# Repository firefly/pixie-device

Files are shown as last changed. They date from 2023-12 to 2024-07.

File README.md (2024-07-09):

Firefly Pixie: Hardware
=======================

The hardware design, schematics and PCB layouts for the Firefly
Pixie Hardware Wallet for Ethereum (and ilk).

- [Firmware](https://github.com/firefly/pixie-firmware)
- [Case](https://github.com/firefly/pixie-case)

See the [CHANGELOG](./CHANGELOG.md) for high-level changes
between board revisions.

Tech Specs
----------

- **Processor:** ESP32-C3 (32-bit RISC-V)
- **Speed:** 160Mhz
- **Memory:** 400kb RAM, 16Mb Flash, 4kb eFuse
- **Inputs:** 4x tactile buttons
- **Outputs:**
  - 240x240px IPS 1.3" display (16-bit color; RGB565)
  - 4x RGB LED (WS2812B; 24-bit color; GRB888)
- **Conectivity:**
  - USB-C (power + JTAG/CDC-ACM)
  - BLE

Contributing
------------

- To modify the files, use [KiCad](https://www.kicad.org) (open-source EDA application)
- Sicne the `git diff` involved in modifying these files is somewhat opaque, please start a discussion first, so any changes can be coordinated

Photos
-----------

See the [output](./output/) folder for rendered schematics, PCBs
and 3D renders along with photos of the various revisions.

<p align="center">
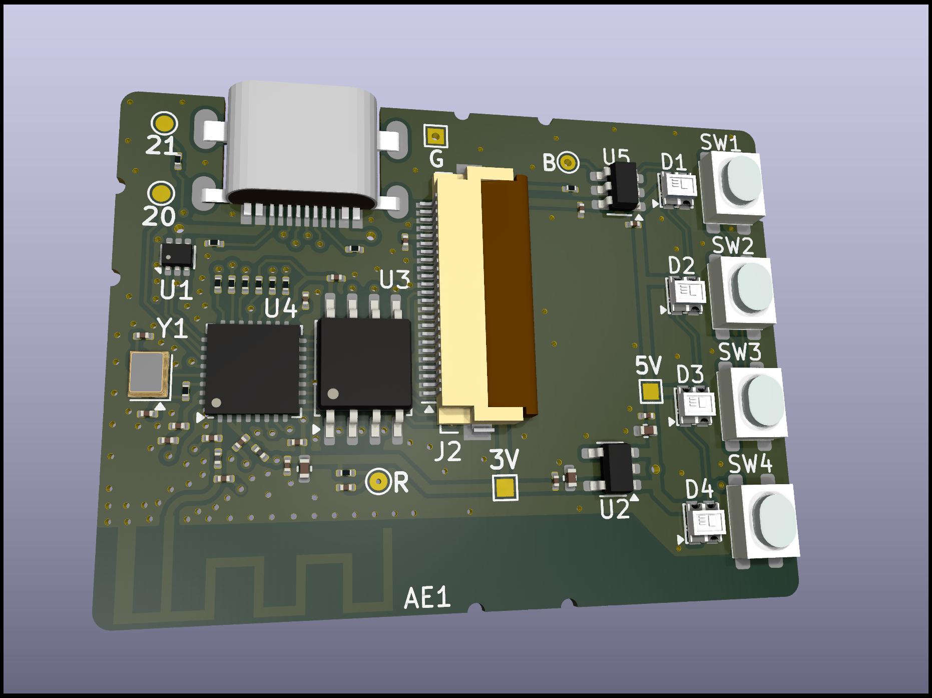
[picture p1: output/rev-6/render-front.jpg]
Front of Firefly Pixie
  
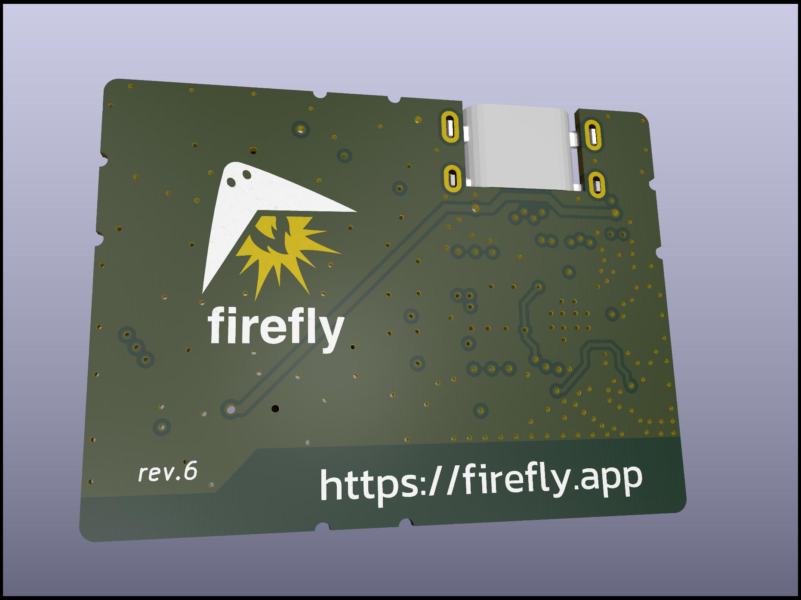
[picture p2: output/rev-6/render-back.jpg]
Back of Firefly Pixie
  
</p>

License
-------

MIT License.

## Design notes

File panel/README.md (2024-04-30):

Panelize
========

This folder uses [KiKit](https://github.com/yaqwsx/KiKit/tree/master) to
create panelized versions of the Firefly Pixie device.

Usage
-----

First, it is important to ensure the KiCad-specific Python runtime has
the KiKit library installed:

```shell
# MacOS
/Users/firefly> /Applications/KiCad/KiCad.app/Contents/Frameworks/Python.framework/Versions/Current/bin/pip3 install KiKit

# Windows
@TODO

# Linux
@TODO
```

Then the `./panelize.sh` can be run in this folder, which creates the
output `panel.kicad_pcb` in the same folder.

```shell
/Users/firefly/pixie-device/panel> ./panelize.sh
```

Renders
-------

<p align="center">
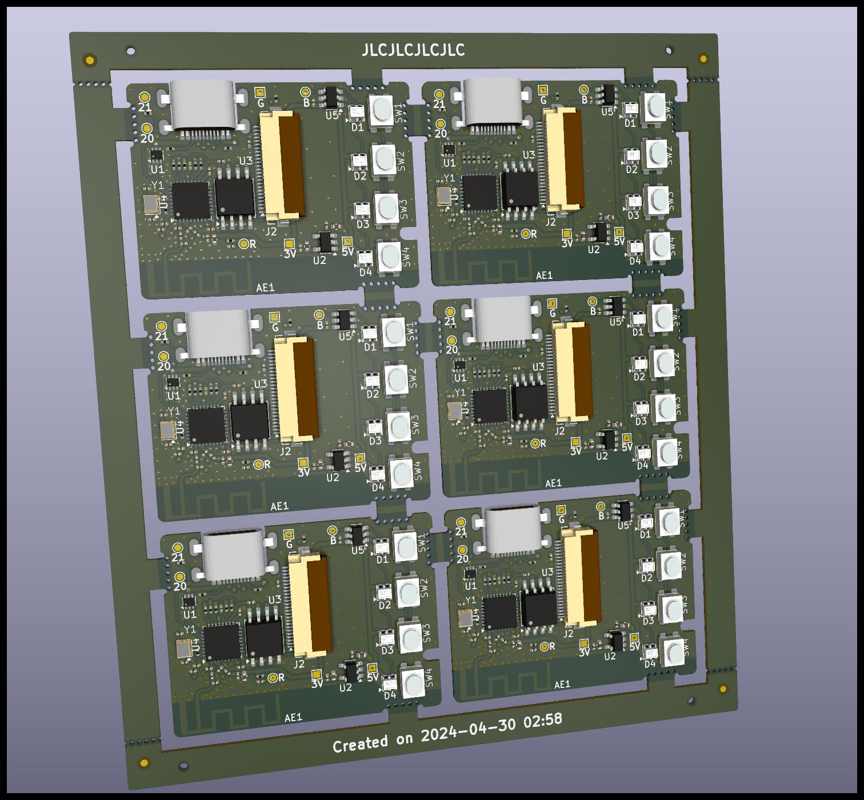
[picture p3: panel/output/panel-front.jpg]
Front of Firefly Pixie panel
  
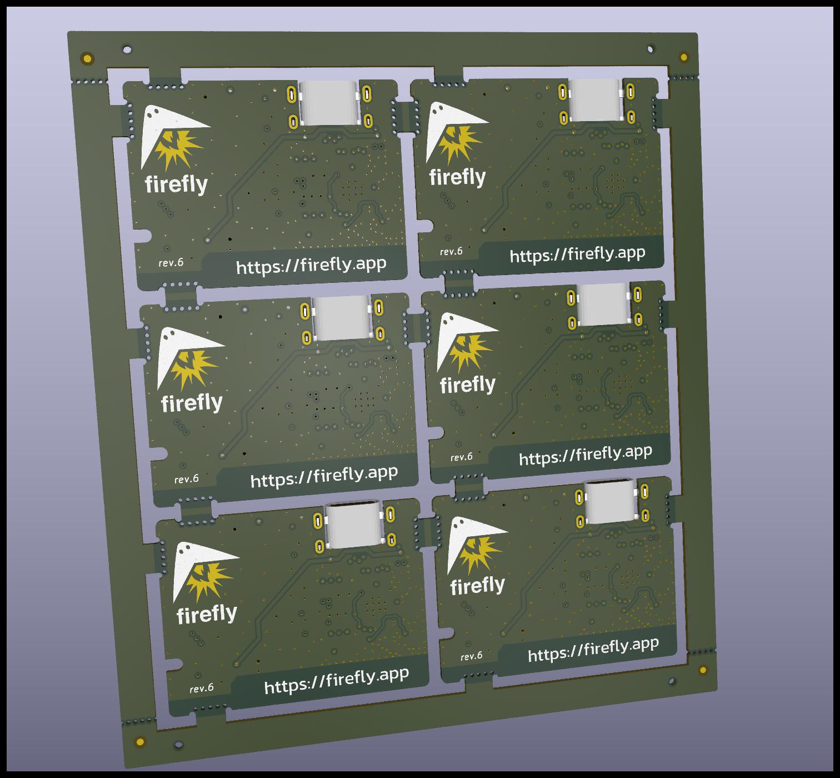
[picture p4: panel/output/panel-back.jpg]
Back of Firefly Pixie panel
  
</p>

<p align="center">
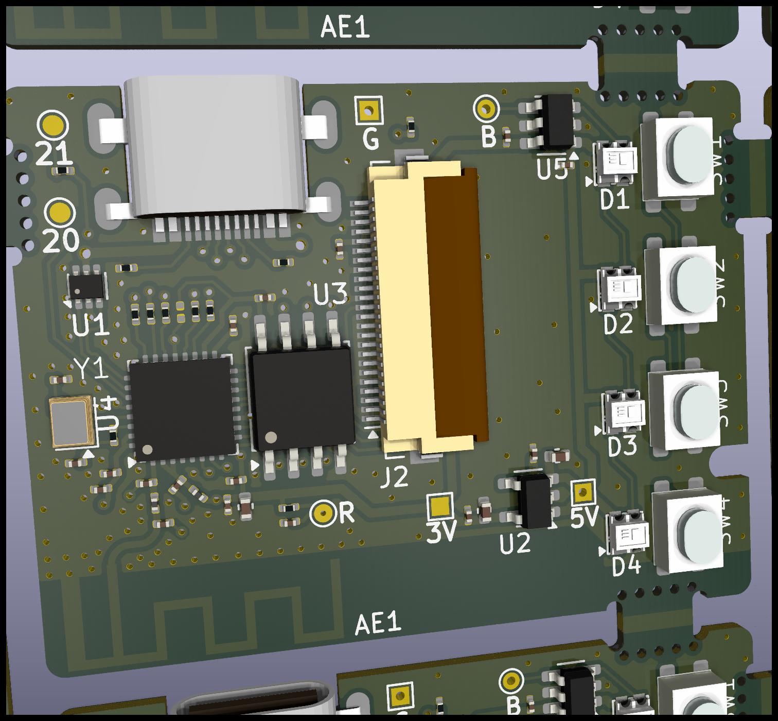
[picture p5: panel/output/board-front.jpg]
Front of Firefly Pixie panel single board
  
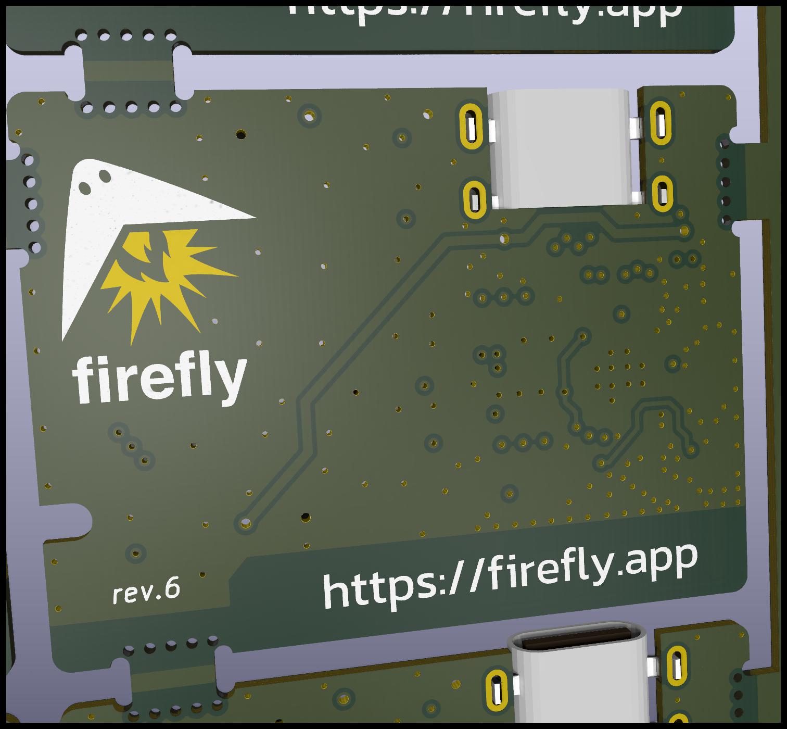
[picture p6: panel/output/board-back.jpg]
Back of Firefly Pixie panel single board
  
</p>

Notes
-----

If moving the tabs in the Firefly Pixie KiCad project (in the parent
folder), make sure to follow the convention it uses for tabs, to ensure
this panelize works correctly:

- The tab must be 4.4mm long, with a 0.5mm radius 180deg arc on both sides
- The "Tab" footprint should be flush and cneter with the tab,with its width set to "4.4mm"

License
-------

All files are licensed under the MIT license.

The PCB Footprints used are licensed uder the MIT license by KiKit.

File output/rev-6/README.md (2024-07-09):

Rev.6
=====

Schematic
---------

<p align="center">
  Schematic of Firefly Pixie: Blocks
  Schematic of Firefly Pixie: Power
</p>
<p align="center">
  Schematic of Firefly Pixie: MCU
  Schematic of Firefly Pixie: Output
</p>

3D Renders
----------

<p align="center">
  Front of Firefly Pixie Device
  Back of Firefly Pixie Device
</p>

<p align="center">
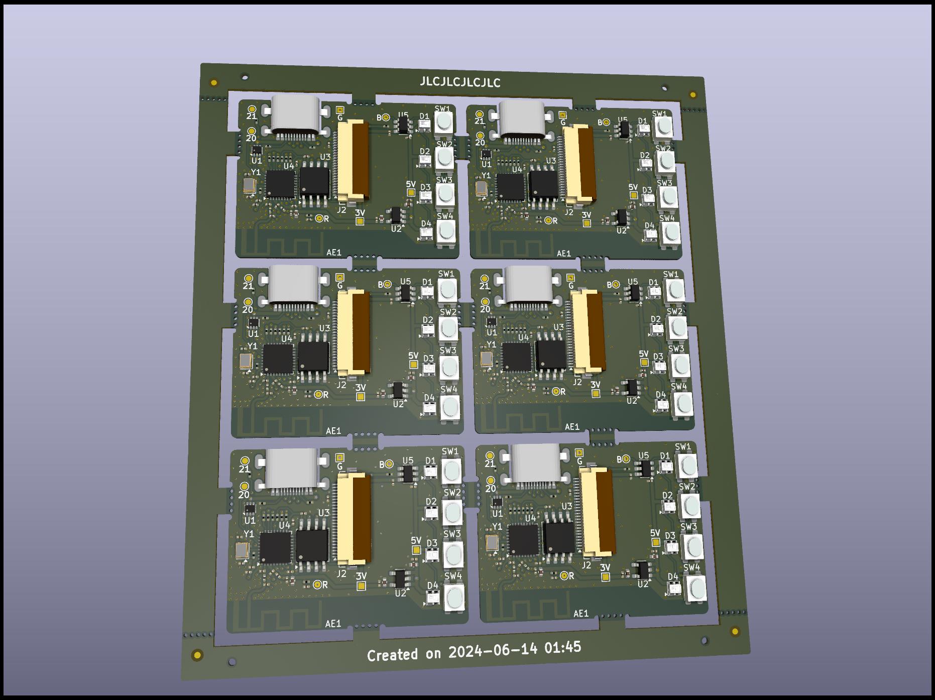
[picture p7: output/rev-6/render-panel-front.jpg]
Front of Firefly Pixie Panel
  
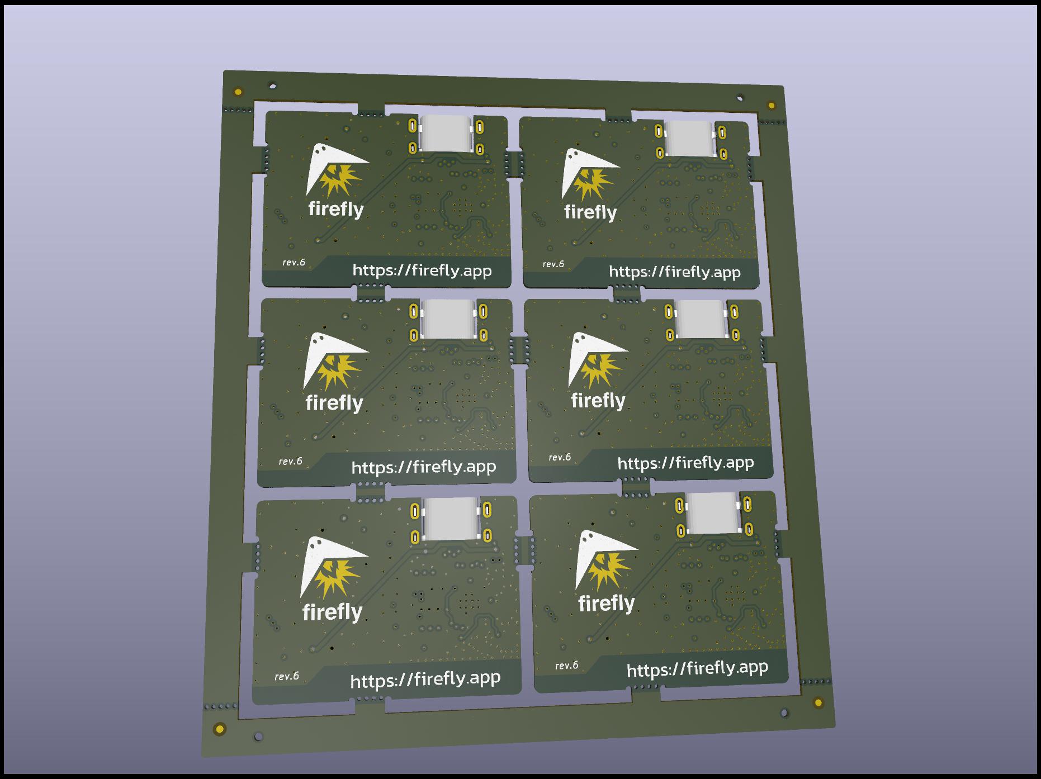
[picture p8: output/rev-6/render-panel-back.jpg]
Back of Firefly Pixie Panel
  
</p>

Photos
------

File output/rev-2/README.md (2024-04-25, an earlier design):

Rev.2
=====

Schematic
---------

<p align="center">
  Schematic of Firefly Pixie
</p>

3D Renders
----------

<p align="center">
  Front of Firefly Pixie
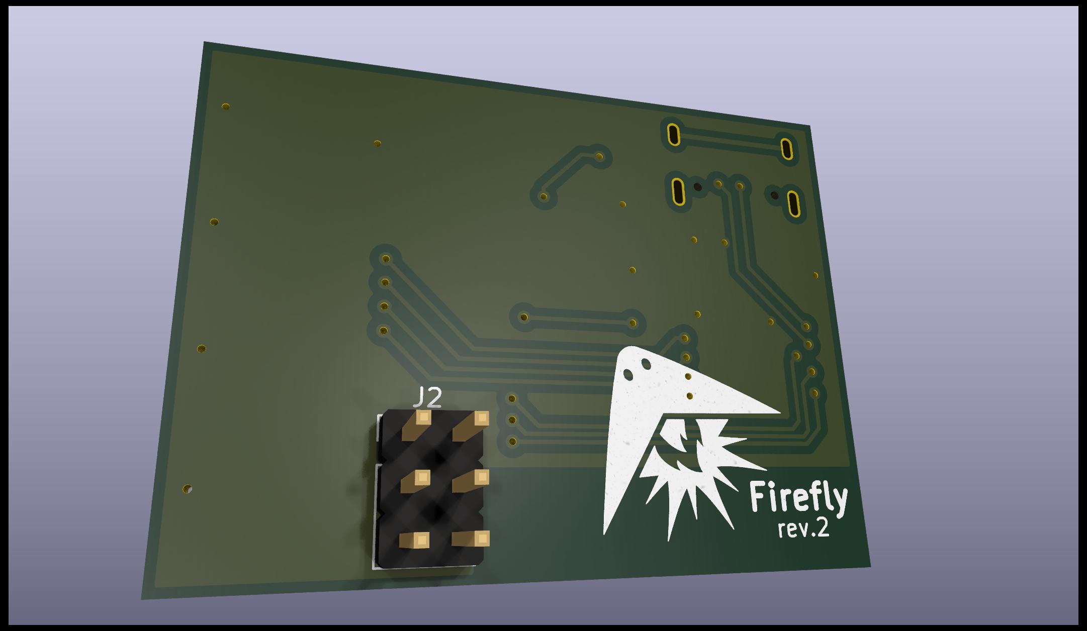
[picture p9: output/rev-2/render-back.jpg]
Back of Firefly Pixie
  
</p>

Photos
------

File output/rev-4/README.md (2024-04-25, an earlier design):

Rev.4
=====

Schematic
---------

<p align="center">
  Schematic of Firefly Pixie: Blocks
  Schematic of Firefly Pixie: Power
</p>
<p align="center">
  Schematic of Firefly Pixie: MCU
  Schematic of Firefly Pixie: Output
</p>

3D Renders
----------

<p align="center">
  Front of Firefly Pixie
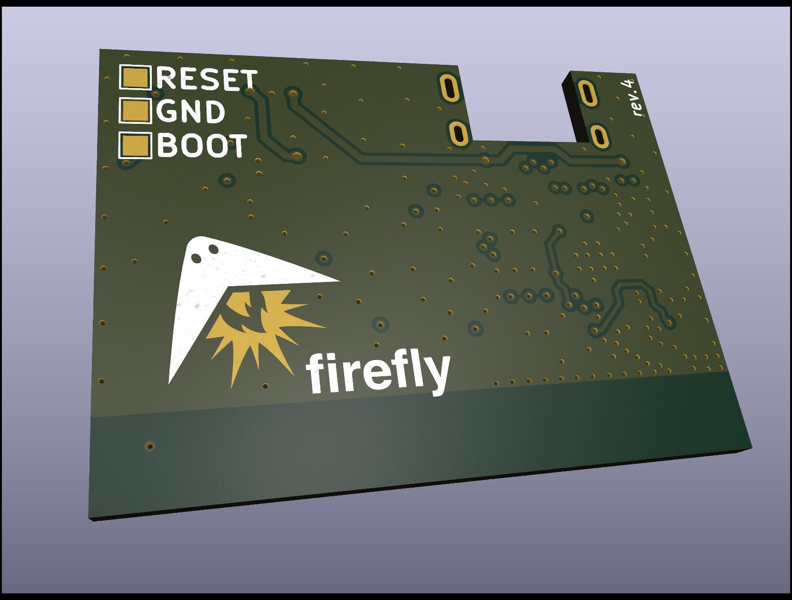
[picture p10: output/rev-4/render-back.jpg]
Back of Firefly Pixie
  
</p>

Photos
------

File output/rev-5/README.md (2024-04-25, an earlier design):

Rev.5
=====

Schematic
---------

<p align="center">
  Schematic of Firefly Pixie: Blocks
  Schematic of Firefly Pixie: Power
</p>
<p align="center">
  Schematic of Firefly Pixie: MCU
  Schematic of Firefly Pixie: Output
</p>

3D Renders
----------

<p align="center">
  Front of Firefly Pixie Panel
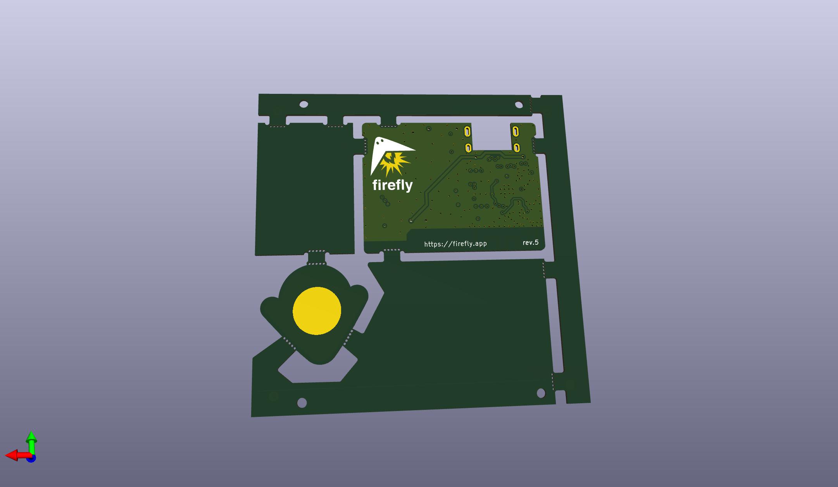
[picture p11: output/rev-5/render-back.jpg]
Back of Firefly Pixie Panel
  
</p>

<p align="center">
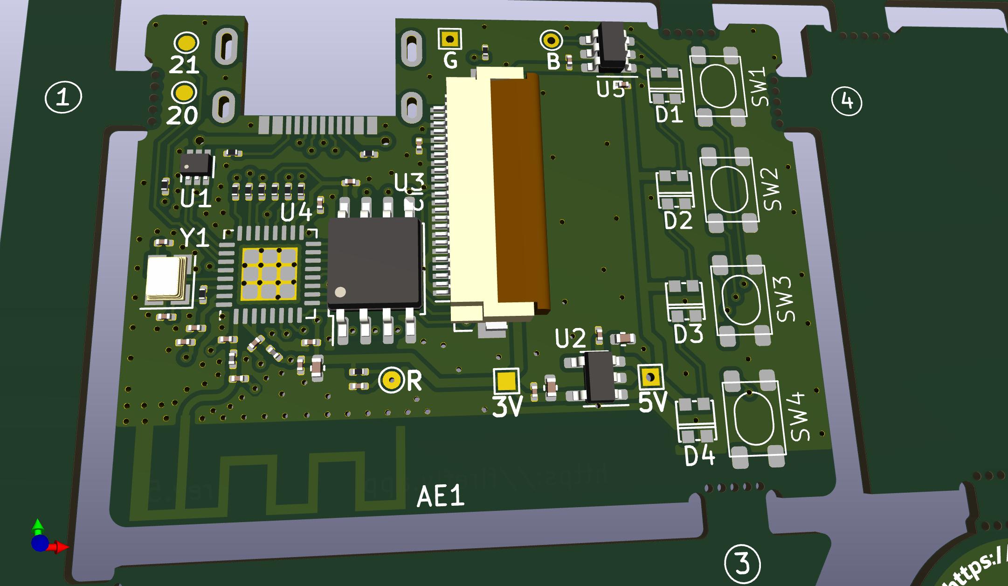
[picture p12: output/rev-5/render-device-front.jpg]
Front of Firefly Pixie Device
  
  Back of Firefly Pixie Device
</p>

<p align="center">
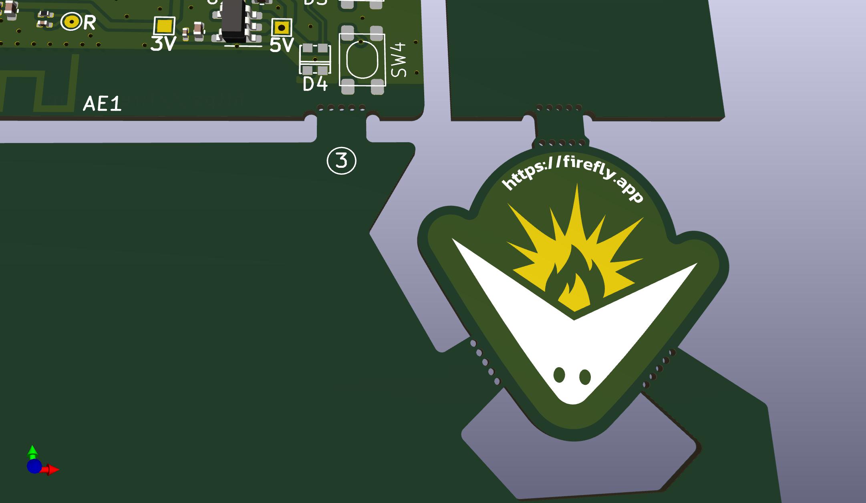
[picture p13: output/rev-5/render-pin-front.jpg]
Front of Firefly Pin
  
  Back of Firefly Pin
</p>

Photos
------

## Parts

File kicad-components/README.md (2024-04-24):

Firefly Compnoent Library
=========================

A bunch of random symbols and footprints for various
devices used for Firefly devices, development boards
and other tools.

License
-------

MIT License.

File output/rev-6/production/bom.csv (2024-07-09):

Designator | Footprint | Quantity | Value | LCSC Part #
C1_6, C1_5, C1_4, C1_3, C1_2, C1, C17_6, C17_5, C17_4, C17_3, C17_2, C17, C4_6, C4_5, C4_4, C4_3, C4_2, C4 | 0402 | 18 | 10u | C315248
C10_6, C10_5, C10_4, C10_3, C10_2, C10, C12_6, C12_5, C12_4, C12_3, C12_2, C12 | 0201 | 12 | 1u | C170153
C11_6, C11_5, C11_4, C11_3, C11_2, C11, C13_6, C13_5, C13_4, C13_3, C13_2, C13, C15_6, C15_5, C15_4, C15_3, C15_2, C15, C16_6, C16_5, C16_4, C16_3, C16_2, C16, C18_6, C18_5, C18_4, C18_3, C18_2, C18, C19_6, C19_5, C19_4, C19_3, C19_2, C19, C2_6, C2_5, C2_4, C2_3, C2_2, C2, C20_6, C20_5, C20_4, C20_3, C20_2, C20, C3_6, C3_5, C3_4, C3_3, C3_2, C3, C7_6, C7_5, C7_4, C7_3, C7_2, C7 | 0201 | 60 | 100n | C284966
C14_6, C14_5, C14_4, C14_3, C14_2, C14 | 0201 | 6 | 10n | C76941
C5_6, C5_5, C5_4, C5_3, C5_2, C5, C8_6, C8_5, C8_4, C8_3, C8_2, C8 | 0201 | 12 | 3p3 | C258460
C6_6, C6_5, C6_4, C6_3, C6_2, C6, C9_6, C9_5, C9_4, C9_3, C9_2, C9 | 0201 | 12 | 10p | C272871
D1_6, D1_5, D1_4, D1_3, D1_2, D1, D2_6, D2_5, D2_4, D2_3, D2_2, D2, D3_6, D3_5, D3_4, D3_3, D3_2, D3, D4_6, D4_5, D4_4, D4_3, D4_2, D4 | WS2812B | 24 | WS2812B | C2976072
J1_6, J1_5, J1_4, J1_3, J1_2, J1 | USB_C_SINK | 6 | ~ | C2906289
J2_6, J2_5, J2_4, J2_3, J2_2, J2 | JUSHUO_FPC_24 | 6 | ~ | C262669
L1_6, L1_5, L1_4, L1_3, L1_2, L1, L2_6, L2_5, L2_4, L2_3, L2_2, L2 | 0201 | 12 | 2n2 | C98041
R1_6, R1_5, R1_4, R1_3, R1_2, R1, R2_6, R2_5, R2_4, R2_3, R2_2, R2, R3_6, R3_5, R3_4, R3_3, R3_2, R3 | 0201 | 18 | 5K1 | C274341
R10_6, R10_5, R10_4, R10_3, R10_2, R10, R6_6, R6_5, R6_4, R6_3, R6_2, R6, R7_6, R7_5, R7_4, R7_3, R7_2, R7, R8_6, R8_5, R8_4, R8_3, R8_2, R8, R9_6, R9_5, R9_4, R9_3, R9_2, R9 | 0201 | 30 | 100R | C77623
R11_6, R11_5, R11_4, R11_3, R11_2, R11 | 0201 | 6 | 499R | C4354889
R12_6, R12_5, R12_4, R12_3, R12_2, R12 | 0201 | 6 | 10R | C304508
R4_6, R4_5, R4_4, R4_3, R4_2, R4 | 0201 | 6 | 22R | C270355
SW1_6, SW1_5, SW1_4, SW1_3, SW1_2, SW1, SW2_6, SW2_5, SW2_4, SW2_3, SW2_2, SW2, SW3_6, SW3_5, SW3_4, SW3_3, SW3_2, SW3, SW4_6, SW4_5, SW4_4, SW4_3, SW4_2, SW4 | button-oval | 24 | ~ | C720479
U1_6, U1_5, U1_4, U1_3, U1_2, U1 | SOT-563 | 6 | USBLC6-2SC6 | C2827693
U2_6, U2_5, U2_4, U2_3, U2_2, U2 | SOT-23-5 | 6 | SPX3819M5-L-3-3 | C5370980
U3_6, U3_5, U3_4, U3_3, U3_2, U3 | SOIC-8_5.23x5.23mm_P1.27mm | 6 | W25Q128JVS | C97521
U4_6, U4_5, U4_4, U4_3, U4_2, U4 | QFN-32-1EP_5x5mm_P0.5mm_EP3.45x3.45mm | 6 | ESP32-C3 | C2838500
U5_6, U5_5, U5_4, U5_3, U5_2, U5 | SOT-23-6 | 6 | SN74LVC1T45DBV | C168856
Y1_6, Y1_5, Y1_4, Y1_3, Y1_2, Y1 | crystal_2520 | 6 | 40Mhz | C409424

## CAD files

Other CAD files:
kicad-components/3d-models/button-oval.skp
kicad-components/3d-models/usb-c-sink-8.skp
kicad-components/3d-models/ws2812c-2020-v1.skp

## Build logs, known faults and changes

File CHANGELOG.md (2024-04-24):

Change Log
==========

Since the KiCAD files don't diff well, this list of changes
is maintained in a relatively manual manner, designed to help
keep developers up to date on the more broad cahnges made to
the device hardware.

Rev.6
-----

- Moved LEDK trace to B.cu (from In2.cu)
- Updated footprint for Crystal to match newer part and allow more space for the GPIO traces
- Updated all files and footprints from KiCAD 7 to KiCAD 8
- Added 3D models for Oval Button and WS2812c
- PCB Batch:
  - X devices
  - ENIG, 0.8mm, mouse-bites, purple mask
  - Panel: 2x3 devices, 100mm x 100mm panel

Rev.5
-----

- added GPIO 20 and 21 pads for debugging and extending hardware interfaces (including adding 499 ohm resistor to GPIO 21)
- Added test points for v5, v3.3, reset, boot and ground for debugging and extending hardware
- Added 3 more LED; one per button
- Use mouse bites instead of V-cut for rounded corners and better exposing the trench for the sunk USB port
- Added firefly pin punch out to test panelizing
- Relocated regulator for better FPC clearance
- Changed FPC part and footprint due to inventory constraints
- Added solder paste to USB shield PTH for better structural support
- PCB Batch
  - 25 devices
  - ENIG, 0.8mm, mouse-bites, green mask
  - Panel (testing): 1 device + 1 pin per, 70mm x 70mm panel

Rev.4
-----

- added LED to button 2 along with level shifter
- change logo flame to B.Mask from silkscreen so exposed copper is used for flame
- Change to Esp32 c3 chip with external 16mb storage (based on the WROOM layout)
- PCB Batch
  - 10 devices
  - HASL, 1.6mm, v-cut, green mask

Rev.2
-----

- Initial ESP32-c3 based device
- Uses ESP32c3-mini-1 module
- PCB Batch
  - 10 devices
  - HASL, 1.6mm, v-cut, green mask

Notes
-----

Early prototypes were based on ATmega and had multiple versions
in flight, prior to establishing a clear versioning policy. As
such there is a prior `rev.2` board completely unrelated to the

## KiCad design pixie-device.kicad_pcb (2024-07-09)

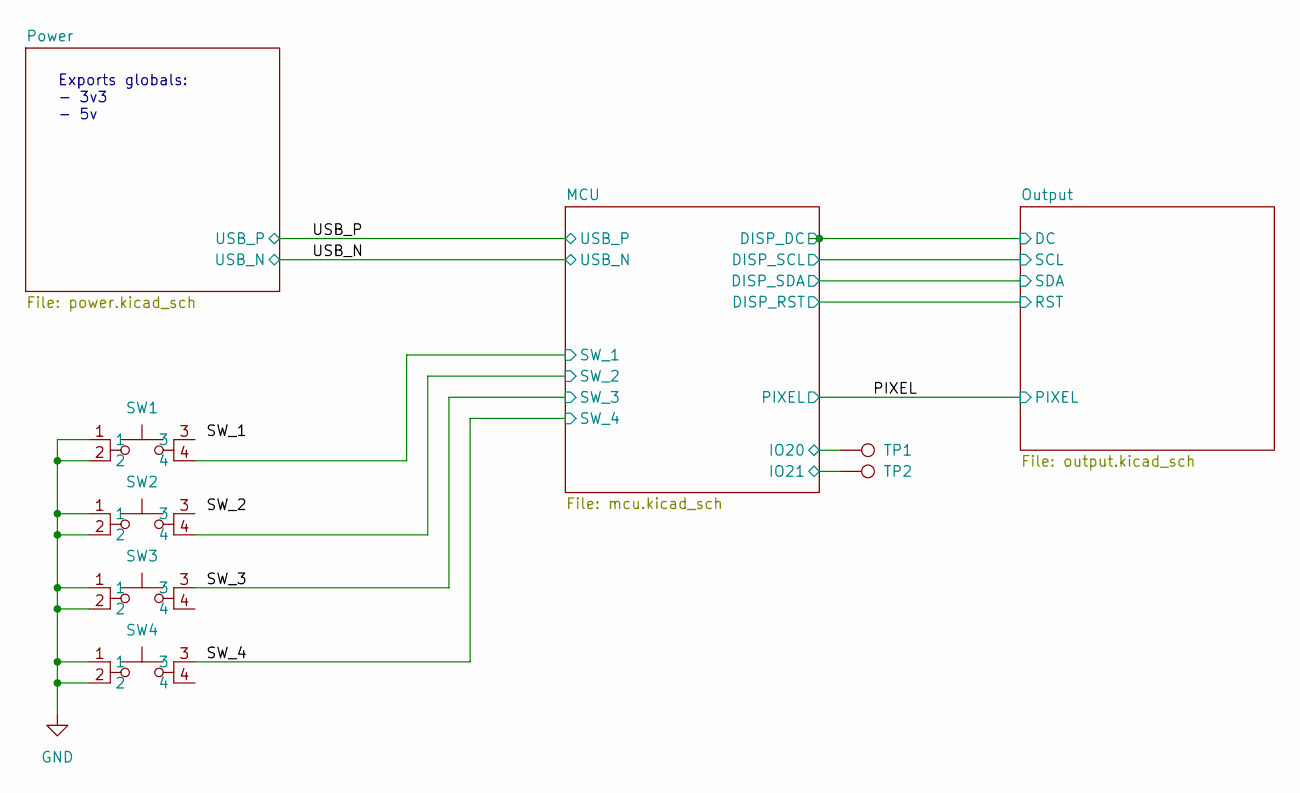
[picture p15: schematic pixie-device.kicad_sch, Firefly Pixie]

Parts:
SW1, SW2, SW3, SW4: button-oval; MPN C720479
TP1, TP2: TestPoint; TestPoint_Pad_D1.0mm

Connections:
/MCU/IO20: TP1.1; also elsewhere on the board
/MCU/IO21: TP2.1; also elsewhere on the board
/MCU/SW_1: SW1.4; also elsewhere on the board
/MCU/SW_2: SW2.4; also elsewhere on the board
/SW_3: SW3.3; also elsewhere on the board
/SW_4: SW4.3; also elsewhere on the board
GND: SW1.1, SW1.2, SW2.1, SW2.2, SW3.1, SW3.2, SW4.1, SW4.2; also elsewhere on the board

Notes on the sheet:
Exports globals: - 3v3 - 5v

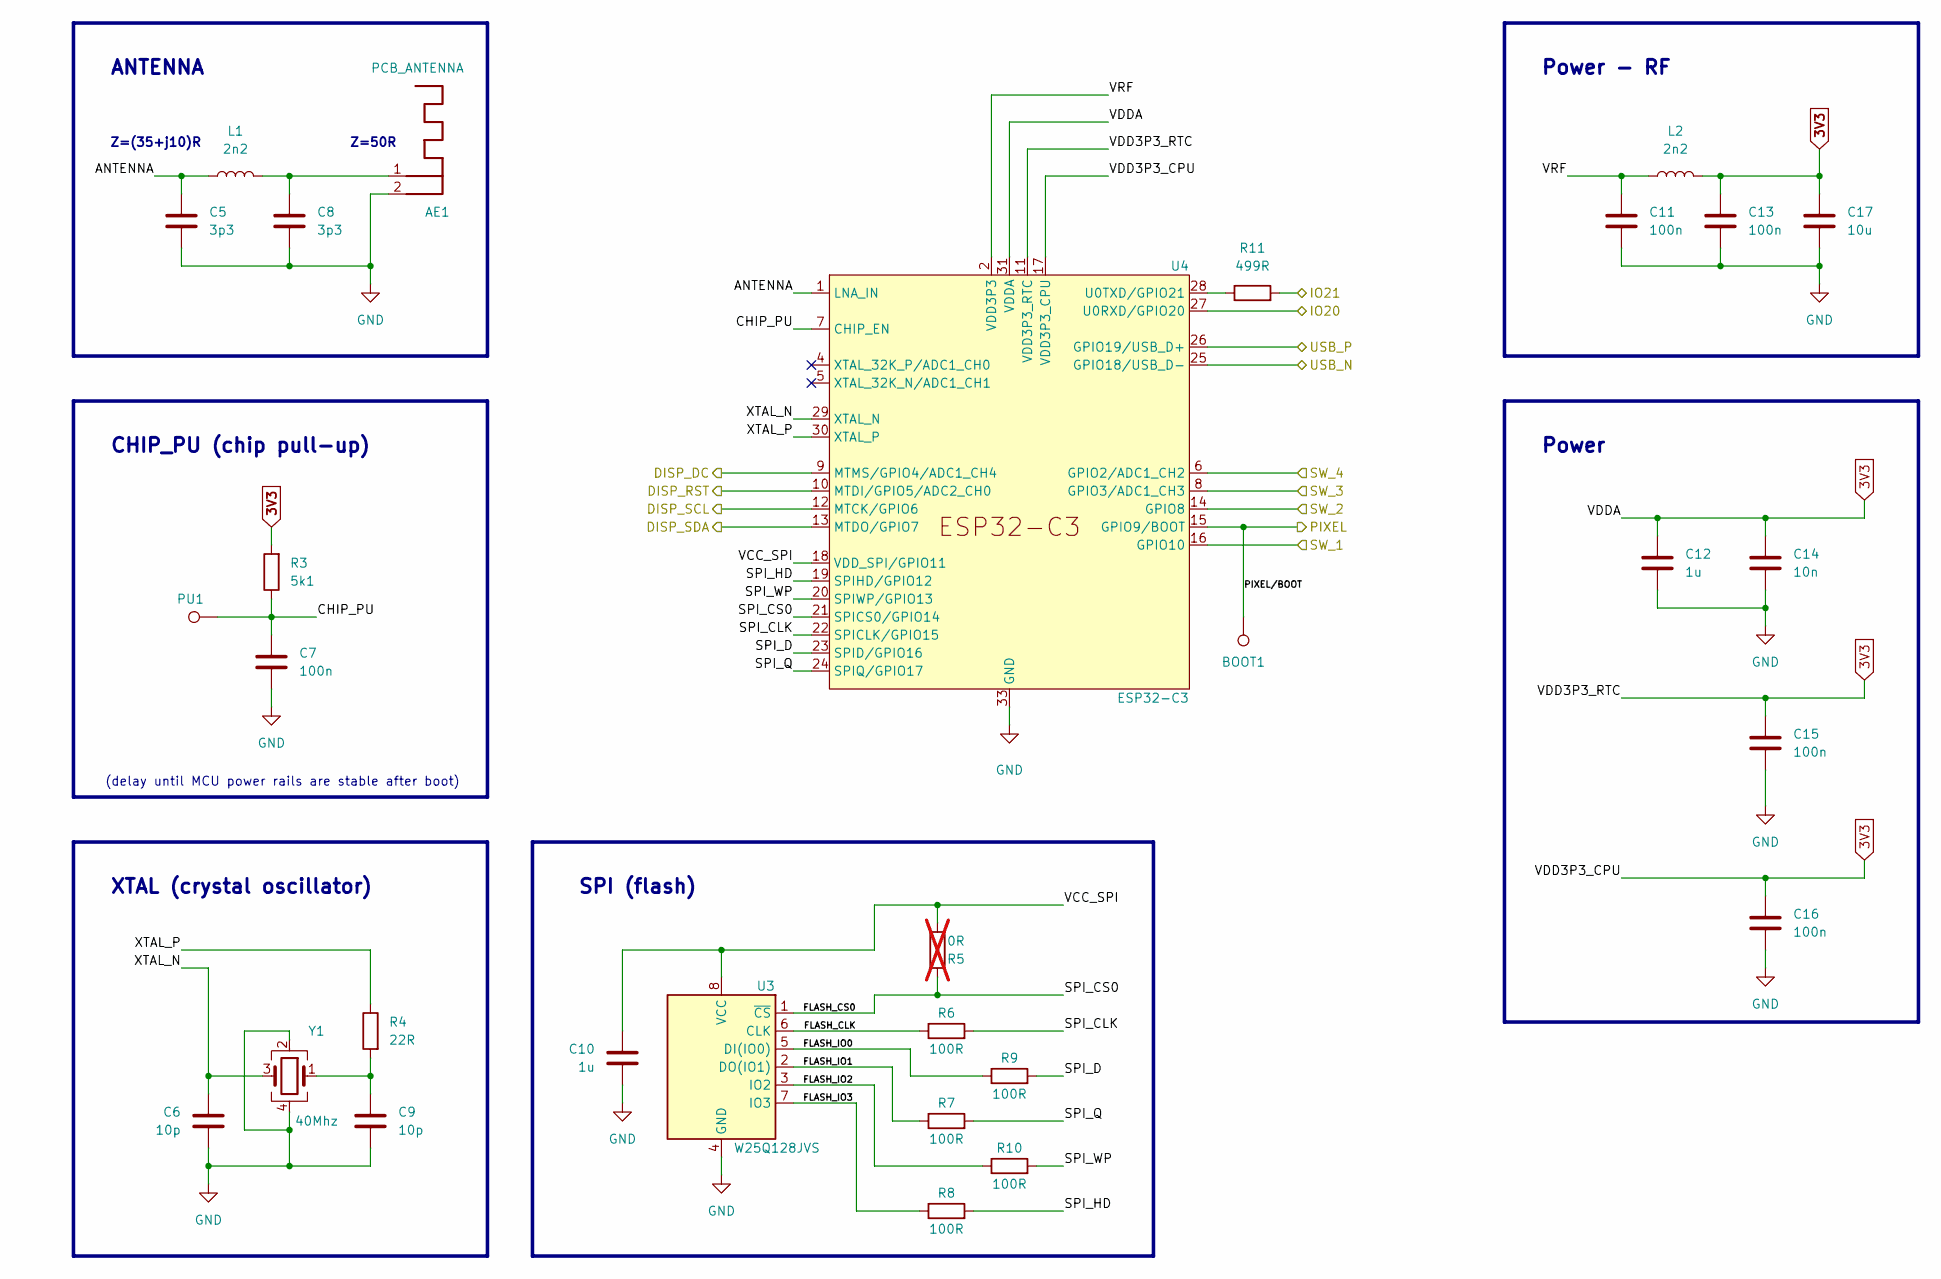
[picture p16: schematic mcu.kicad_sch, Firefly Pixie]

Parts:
AE1: PCB_ANTENNA; PCB_Antenna
BOOT1: TestPoint; TestPoint_Pad_D1.0mm
C5, C8: 3p3; C_0201_0603Metric; MPN C258460
C6, C9: 10p; C_0201_0603Metric; MPN C272871
C7, C11, C13, C15, C16: 100n; C_0201_0603Metric; MPN C284966
C10, C12: 1u; C_0201_0603Metric; MPN C170153
C14: 10n; C_0201_0603Metric; MPN C76941
C17: 10u; C_0402_1005Metric; MPN C315248
L1, L2: 2n2; L_0201_0603Metric; MPN C98041
PU1: TestPoint; TestPoint_Pad_D1.0mm
R3: 5k1; R_0201_0603Metric; MPN C274341
R4: 22R; R_0201_0603Metric; MPN C270355
R5: 0R; R_0201_0603Metric; not fitted
R6, R7, R8, R9, R10: 100R; R_0201_0603Metric; MPN C77623
R11: 499R; R_0201_0603Metric; MPN C4354889
U3: W25Q128JVS; SOIC-8_5.23x5.23mm_P1.27mm; MPN C97521
U4: ESP32-C3; QFN-32-1EP_5x5mm_P0.5mm_EP3.45x3.45mm; MPN C2838500
Y1: 40Mhz; crystal_2520; MPN_old C255973

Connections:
3V3: C12.1, C13.1, C14.1, C15.1, C16.1, C17.1, L2.2, R3.2, U4.11 (VDD3P3_RTC), U4.17 (VDD3P3_CPU), U4.31 (VDDA), U4.32 (VDDA); also elsewhere on the board
/MCU/ANTENNA: C5.1, L1.1, U4.1 (LNA_IN)
/MCU/CHIP_PU: C7.1, PU1.1, R3.1, U4.7 (CHIP_EN)
/MCU/DISP_DC: U4.9 (MTMS/GPIO4/ADC1_CH4); also elsewhere on the board
/MCU/DISP_RST: U4.10 (MTDI/GPIO5/ADC2_CH0); also elsewhere on the board
/MCU/DISP_SCL: U4.12 (MTCK/GPIO6); also elsewhere on the board
/MCU/DISP_SDA: U4.13 (MTDO/GPIO7); also elsewhere on the board
/MCU/FLASH_CLK: R6.1, U3.6 (CLK)
/MCU/FLASH_CS0: R5.2, U3.1 (~CS), U4.21 (SPICS0/GPIO14)
/MCU/FLASH_IO0: R9.1, U3.5 (DI(IO0))
/MCU/FLASH_IO1: R7.1, U3.2 (DO(IO1))
/MCU/FLASH_IO2: R10.1, U3.3 (IO2)
/MCU/FLASH_IO3: R8.1, U3.7 (IO3)
/MCU/IO20: U4.27 (U0RXD/GPIO20); also elsewhere on the board
/MCU/IO21: R11.2; also elsewhere on the board
/MCU/SPI_CLK: R6.2, U4.22 (SPICLK/GPIO15)
/MCU/SPI_D: R9.2, U4.23 (SPID/GPIO16)
/MCU/SPI_HD: R8.2, U4.19 (SPIHD/GPIO12)
/MCU/SPI_Q: R7.2, U4.24 (SPIQ/GPIO17)
/MCU/SPI_WP: R10.2, U4.20 (SPIWP/GPIO13)
/MCU/SW_1: U4.16 (GPIO10); also elsewhere on the board
/MCU/SW_2: U4.14 (GPIO8); also elsewhere on the board
/MCU/VCC_SPI: C10.1, R5.1, U3.8 (VCC), U4.18 (VDD_SPI/GPIO11)
/MCU/VRF: C11.1, L2.1, U4.2 (VDD3P3), U4.3 (VDD3P3)
/MCU/XTAL_N: C6.1, U4.29 (XTAL_N), Y1.3
/MCU/XTAL_P: R4.1, U4.30 (XTAL_P)
/PIXEL: BOOT1.1, U4.15 (GPIO9/BOOT); also elsewhere on the board
/SW_3: U4.8 (GPIO3/ADC1_CH3); also elsewhere on the board
/SW_4: U4.6 (GPIO2/ADC1_CH2); also elsewhere on the board
/USB_N: U4.25 (GPIO18/USB_D-); also elsewhere on the board
/USB_P: U4.26 (GPIO19/USB_D+); also elsewhere on the board
GND: AE1.2, C5.2, C6.2, C7.2, C8.2, C9.2, C10.2, C11.2, C12.2, C13.2, C14.2, C15.2, C16.2, C17.2, U3.4 (GND), U4.33 (GND), Y1.2, Y1.4; also elsewhere on the board
unnamed: AE1.1, C8.1, L1.2
unnamed: C9.1, R4.2, Y1.1
unnamed: R11.1, U4.28 (U0TXD/GPIO21)

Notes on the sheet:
Power - RF
Z=50R
XTAL (crystal oscillator)
Z=(35+j10)R
Power
SPI (flash)
(delay until MCU power rails are stable after boot)
ANTENNA
CHIP_PU (chip pull-up)

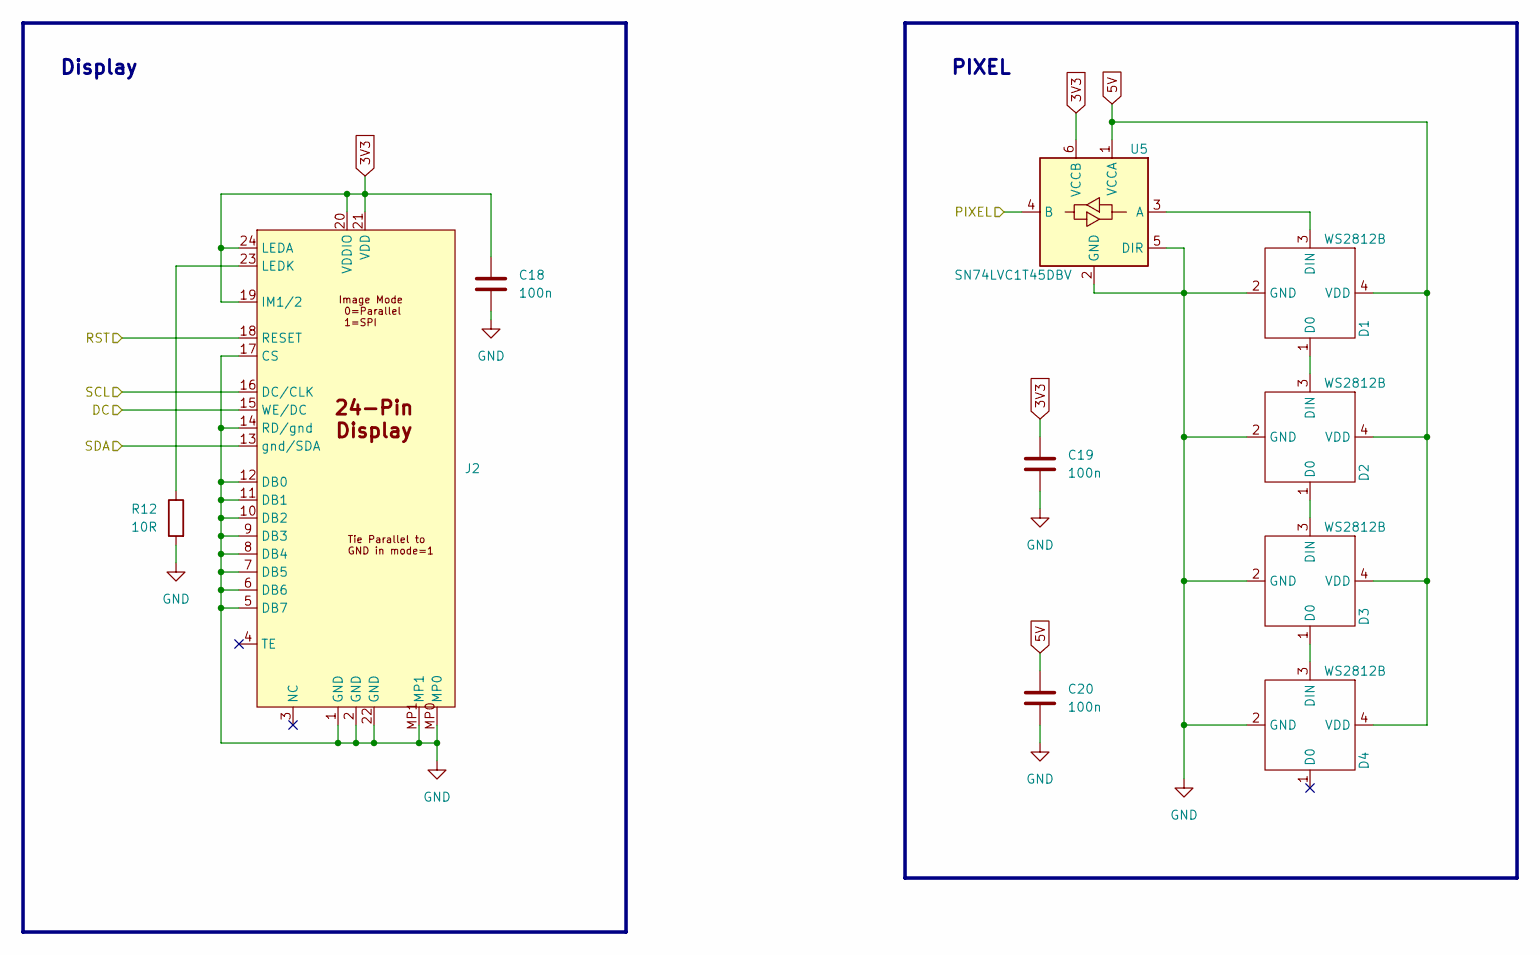
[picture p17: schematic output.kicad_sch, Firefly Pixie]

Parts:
C18, C19, C20: 100n; C_0201_0603Metric; MPN C284966
D1, D2, D3, D4: WS2812B; MPN C2976072
J2: JUSHUO_FPC_24; MPN C262669
R12: 10R; R_0201_0603Metric; MPN C304508
U5: SN74LVC1T45DBV; SOT-23-6; MPN C168856

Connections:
3V3: C18.1, C19.1, J2.19 (IM1/2), J2.20 (VDDIO), J2.21 (VDD), J2.24 (LEDA), U5.6 (VCCB); also elsewhere on the board
5V: C20.1, D1.4 (VDD), D2.4 (VDD), D3.4 (VDD), D4.4 (VDD), U5.1 (VCCA); also elsewhere on the board
/MCU/DISP_DC: J2.15 (WE/DC); also elsewhere on the board
/MCU/DISP_RST: J2.18 (RESET); also elsewhere on the board
/MCU/DISP_SCL: J2.16 (DC/CLK); also elsewhere on the board
/MCU/DISP_SDA: J2.13 (gnd/SDA); also elsewhere on the board
/PIXEL: U5.4 (B); also elsewhere on the board
GND: C18.2, C19.2, C20.2, D1.2 (GND), D2.2 (GND), D3.2 (GND), D4.2 (GND), J2.1 (GND), J2.2 (GND), J2.5 (DB7), J2.6 (DB6), J2.7 (DB5), J2.8 (DB4), J2.9 (DB3), J2.10 (DB2), J2.11 (DB1), J2.12 (DB0), J2.14 (RD/gnd), J2.17 (CS), J2.22 (GND), J2.MP0, J2.MP1, R12.2, U5.2 (GND), U5.5 (DIR); also elsewhere on the board
unnamed: D1.1 (D0), D2.3 (DIN)
unnamed: D1.3 (DIN), U5.3 (A)
unnamed: D2.1 (D0), D3.3 (DIN)
unnamed: D3.1 (D0), D4.3 (DIN)
unnamed: J2.23 (LEDK), R12.1

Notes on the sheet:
Display
PIXEL

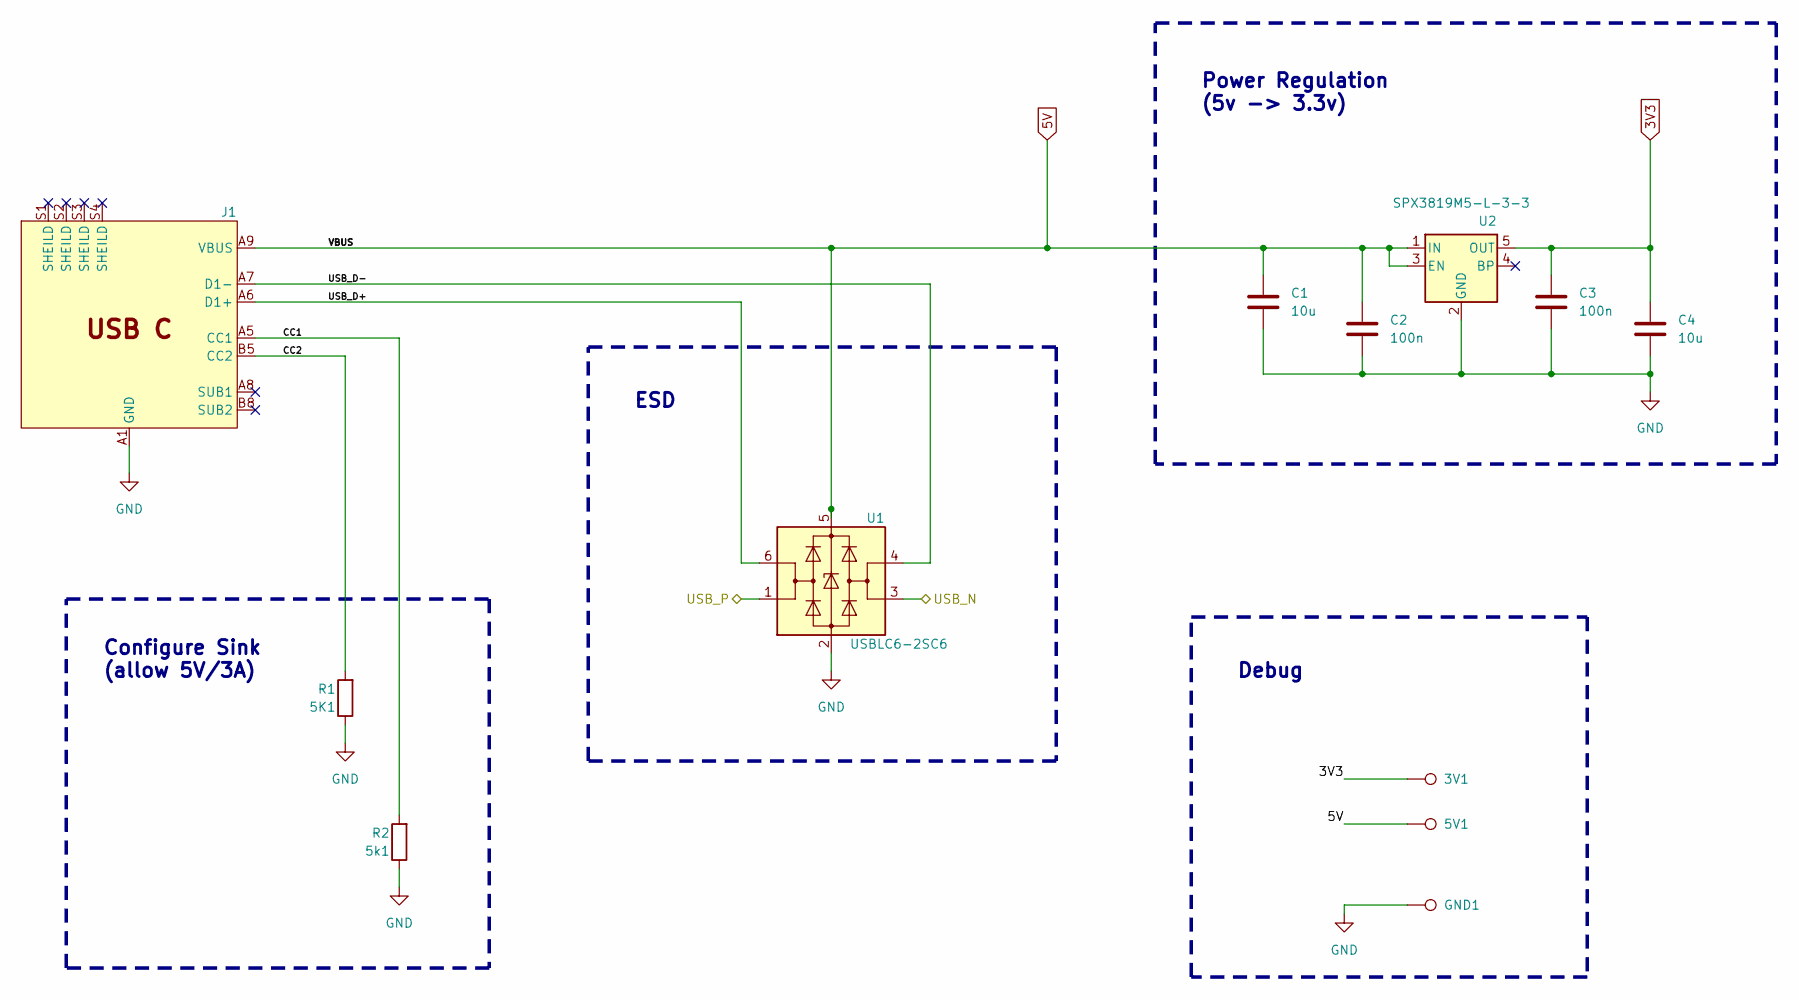
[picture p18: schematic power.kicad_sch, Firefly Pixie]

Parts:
3V1, 5V1: TestPoint; TestPoint_Pad_1.0x1.0mm
C1, C4: 10u; C_0402_1005Metric; MPN C315248
C2, C3: 100n; C_0201_0603Metric; MPN C284966
GND1: TestPoint; TestPoint_Pad_1.0x1.0mm
J1: USB_C_SINK; MPN C2906289
R1: 5K1; R_0201_0603Metric; MPN C274341
R2: 5k1; R_0201_0603Metric; MPN C274341
U1: USBLC6-2SC6; SOT-563; MPN C2827693
U2: SPX3819M5-L-3-3; SOT-23-5; MPN C5370980

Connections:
3V3: 3V1.1, C3.1, C4.1, U2.5 (OUT); also elsewhere on the board
5V: 5V1.1, C1.1, C2.1, J1.A4 (VBUS), J1.A9 (VBUS), J1.B4 (VBUS), J1.B9 (VBUS), U1.5 (VBUS), U2.1 (IN), U2.3 (EN); also elsewhere on the board
/Power/CC1: J1.A5 (CC1), R2.2
/Power/CC2: J1.B5 (CC2), R1.2
/Power/USB_D+: J1.A6 (D1+), J1.B6 (D2+), U1.6 (I/O1)
/Power/USB_D-: J1.A7 (D1-), J1.B7 (D2-), U1.4 (I/O2)
/USB_N: U1.3 (I/O2); also elsewhere on the board
/USB_P: U1.1 (I/O1); also elsewhere on the board
GND: C1.2, C2.2, C3.2, C4.2, GND1.1, J1.A1 (GND), J1.A12 (GND), J1.B1 (GND), J1.B12 (GND), R1.1, R2.1, U1.2 (GND), U2.2 (GND); also elsewhere on the board

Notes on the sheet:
Power Regulation (5v -> 3.3v)
Configure Sink (allow 5V/3A)
ESD
Debug

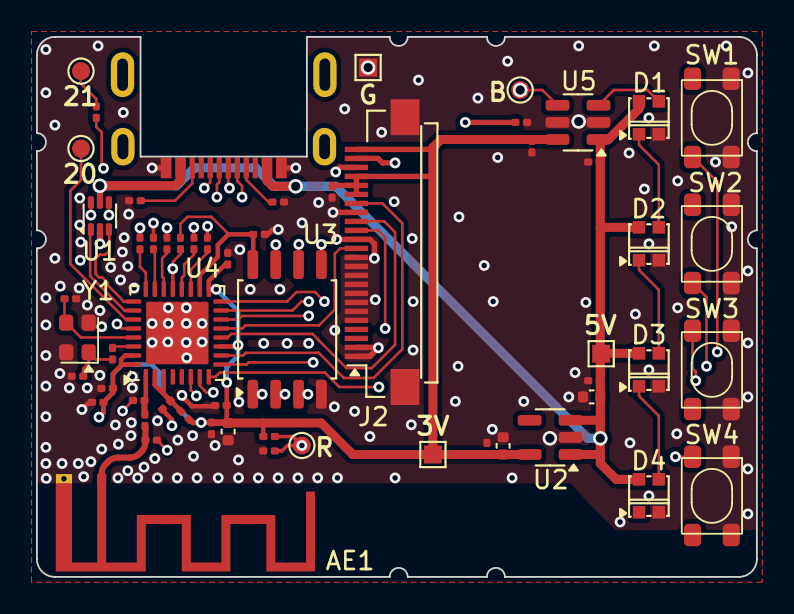
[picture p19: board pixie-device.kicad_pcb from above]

Board: 4 copper layers, 40.0 x 30.0 mm, 58 parts (0 on the bottom side), 45 nets.

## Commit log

2023-10-12 Initial code drop.
    [pixie-rev-4.kicad_pcb, pixie-rev-4.kicad_sch]
2023-10-12 Added screenshots.
    [pixie-rev-4.kicad_pcb]
2023-10-12 Made U4 ref visible.
    [pixie-rev-4.kicad_pcb]
2023-10-14 Check-in before trying ESP32-C3-F4.
    [pixie-rev-4.kicad_pcb, pixie-rev-4.kicad_sch]
2023-10-24 Checking in before updating against ESP32-C3-WROOM-02 designs.
    [pixie-rev-4.kicad_pcb, pixie-rev-4.kicad_sch]
2023-12-09 JLCPCB Submit
    [pixie-rev-4.kicad_pcb, pixie-rev-4.kicad_sch]
2023-12-09 Added missing sub-sheets.
    [mcu.kicad_sch, output.kicad_sch, power.kicad_sch]
2024-04-06 Checking in before submitting rev.5 to JLCPCB.
    [mcu.kicad_sch, output.kicad_sch, pixie-rev-4.kicad_pcb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]
2024-04-23 Added 3D models for button and LED.
    [button-oval.skp, ws2812c-2020-v1.skp]
2024-04-23 Updated changes for KiCAD 8.
    [mcu.kicad_sch, output.kicad_sch, pixie-rev-4.kicad_pcb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]
2024-04-23 Renamed project from pixie-rev-4 to pixie-device.
    [mcu.kicad_sch, output.kicad_sch, pixie-device.kicad_pcb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]
2024-04-24 Added KiCad components.
    [button-oval.skp, pixie-device.kicad_pcb, ws2812c-2020-v1.skp]
2024-04-24 Remove dead file references to 3d models.
    [button-oval.skp, ws2812c-2020-v1.skp]
2024-04-24 Added Firefly KiCad component libraries to project.
2024-04-24 Updated components for KiCad 8.
2024-04-24 Use ESP suggested C3 footprint and update for KiCad 8.
    [mcu.kicad_sch, output.kicad_sch, pixie-device.kicad_pcb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]
2024-04-24 Added USB-C sink 3D model.
    [usb-c-sink-8.skp]
2024-04-24 Moved GPIO 20 and 21 around.
    [pixie-device.kicad_pcb]
2024-04-25 Removed old unused footprints.
2024-04-25 Added new-style pin 1 designator to footprints.
2024-04-25 Added keywords to footprints.
2024-04-25 Tweaked materials for 3D models.
    [ws2812c-2020-v1.skp]
2024-04-25 Tweaked placements; GPIO 20 and 21.
    [pixie-device.kicad_pcb]
2024-04-25 docs: focus readme on device renders.
2024-04-30 Added panelization using KiKit.
    [pixie-device.kicad_pcb]
2024-04-30 Added historic JLCPCB production files.
    [bom-jlcpcb.csv, bom.csv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]
2024-04-30 Fixed historic schematics lost during export.
2024-06-08 Nove mouse bite tabs for better panel strength.
    [pixie-device.kicad_pcb]
2024-07-09 Move buttons and LEDs 2mm right to accomodate thumb space between the screen.
    [pixie-device.kicad_pcb]
2024-07-09 Added prodction files used for the rev.6.
    [bom.csv, positions.csv]
